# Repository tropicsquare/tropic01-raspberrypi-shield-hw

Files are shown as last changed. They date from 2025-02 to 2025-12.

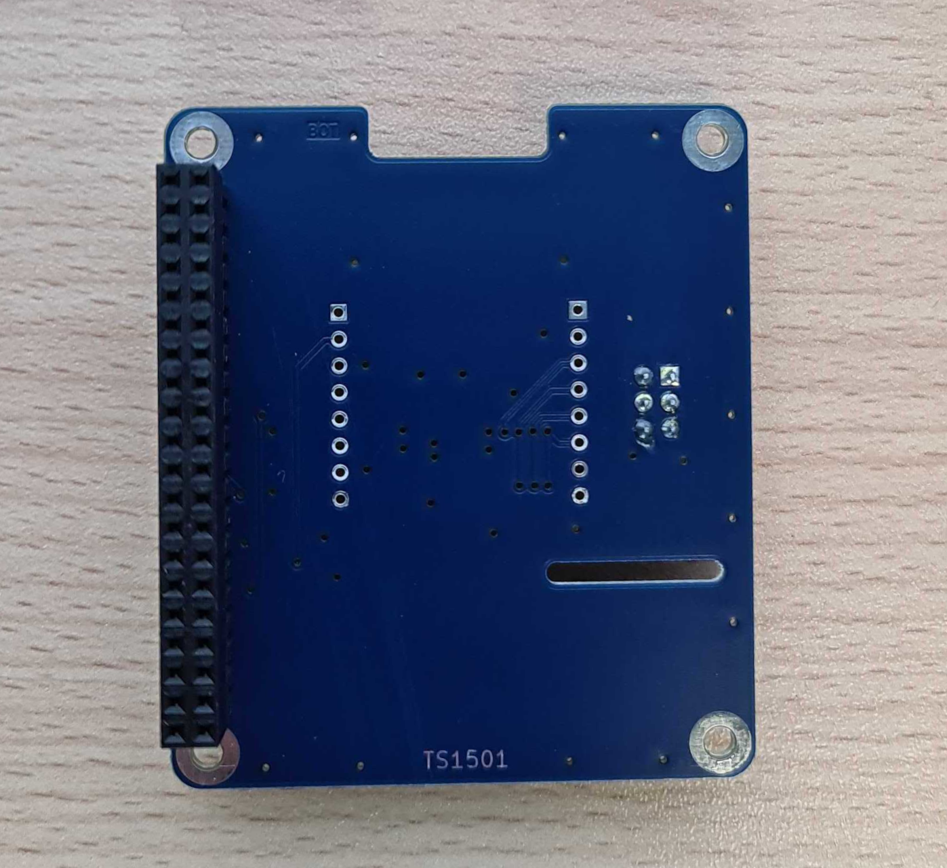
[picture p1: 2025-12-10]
TS1501_design/img/bot_assembled.png

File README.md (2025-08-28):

# TROPIC01 Raspberry Pi Shield

This repository contains the design files for the TROPIC01 development shield, designed for the Raspberry Pi form factor. Each folder corresponds to a specific PCB revision.

### About TROPIC01

For more information about the TROPIC01 secure element, please see the official documentation:

*   [TROPIC01 Datasheet](https://github.com/tropicsquare/tropic01/tree/main/doc/datasheet)
*   [TROPIC01 Website](https://www.tropicsquare.com/tropic01)

# Raspberrypi Shield's Versions

Following table shows all versions of distributed shields.

| hw revision | Picture |
|---|---|
| 1501 |  [Top](./TS1501_design/img/top.png) |

# Getting Started

To interact with the TROPIC01 chip on Linux-based systems like Raspberry Pi OS and Ubuntu, we provide the [`libtropic-linux`](https://github.com/tropicsquare/libtropic-linux) repository, containing integration examples of our platform-independent SDK, [`libtropic`](https://github.com/tropicsquare/libtropic).

 > [!IMPORTANT]
 > Before you start with various examples, we strongly recommend to do two things first:
 > * Read CHIP ID and TROPIC01's firmware versions and **save printed output for future reference**
 > * Update TROPIC01's both internal firmware to latest version.

In [`libtropic-linux`](https://github.com/tropicsquare/libtropic-linux) repository, you can find specifice instruction for both operations based on hardware you use.

### Command line utility

Once you saved results of `show_chip_id_and_fw_ver` example (for future reference) and after your chip is updated with `fw_update` example, you can test our comand line application. Check out [`lt-util`](https://github.com/tropicsquare/libtropic-util) repository, you can find there specifice instruction based on hardware you use.

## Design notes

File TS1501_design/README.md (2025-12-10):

# About

TS15 – TROPIC01 Raspberry Pi Shield
A KiCad-based hardware project designed to connect the TROPIC01 device to a Raspberry Pi via the standard 40-pin GPIO header.

This shield enables straightforward integration of TROPIC01 into Raspberry Pi-based development and testing environments.
It is intended for development, evaluation, and prototyping use.

# Project structure

* `*.kicad_pro` - KiCad project file
* `*.kicad_sch` - Schematic file
* `*.kicad_pcb` - PCB layout file
* `./out/` -  Generated Gerber files for PCB manufacturing
* `./bom/` - Bill of materials, including order codes and interactive BOM
* `./img/` - Images (e.g. PCB renders)
* `*_schematics.pdf` - Exported schematic diagrams (latest version)

# Manufacturing instructions:

## Assembly

IC1/CON1: Chose one variant, assembly IC1 or CON1 (not both on one board).
Chose `bom/bom_variant_*`.

J1: Because the Raspberry Pi has male GPIO pins, the shield's socket must be assembled on the bottom side 
to connect properly when placed on top of the Pi. \

J2: Jumper place to position CS2

There are no any special requirements for C and R components.
Where not specified the R tolerance is 5% and C 20%.

## PCB

* Number of cu layers: 2
* Board Thickness: 1.6
* Core: FR4
* Size: 56 x 65mm
* Mask: Blue
* Silkscreen: Yes (TOP only)

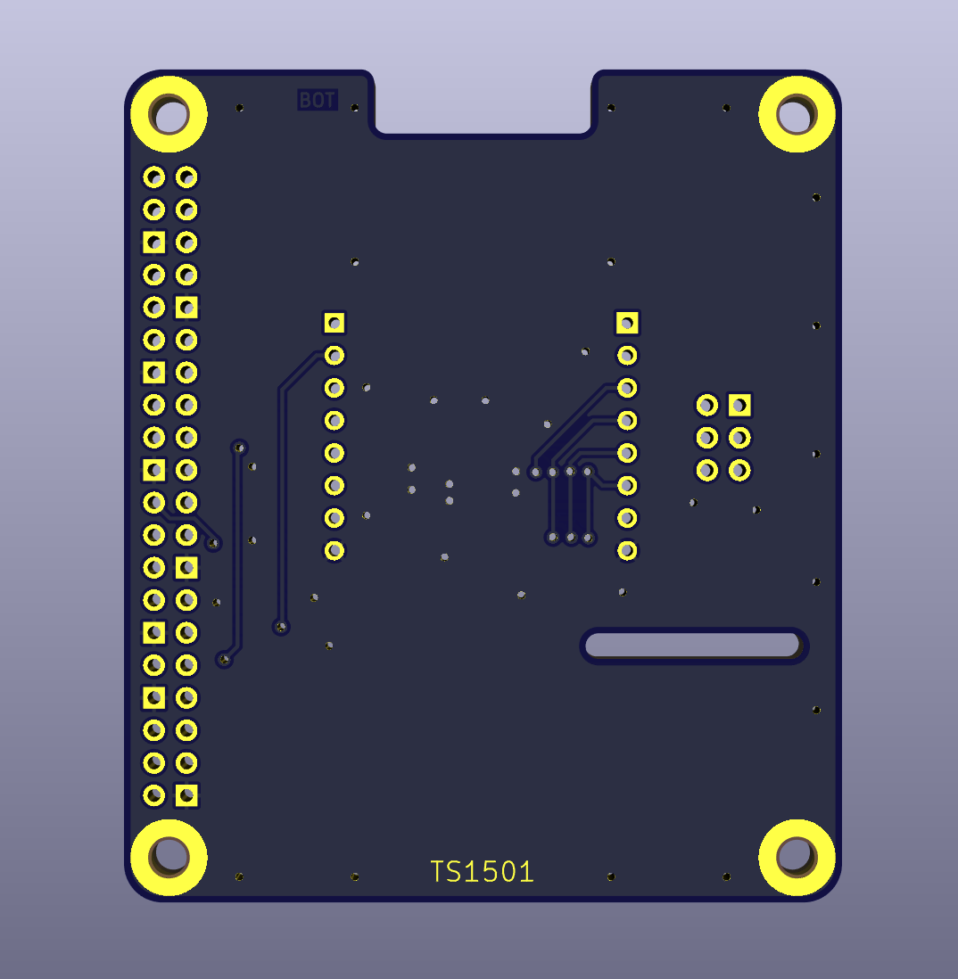
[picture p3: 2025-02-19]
TS1501_design/img/bot.png

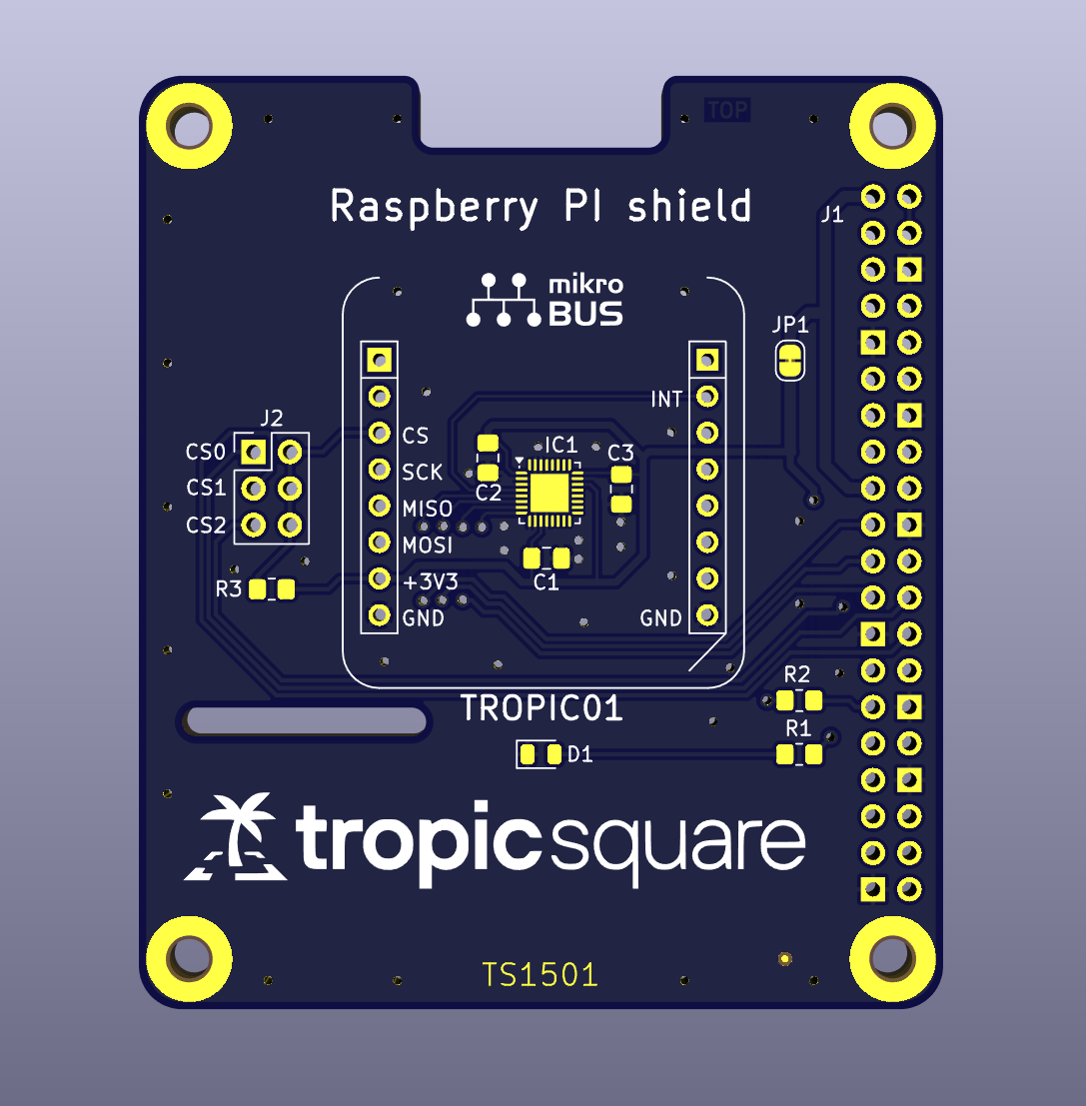
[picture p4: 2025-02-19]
TS1501_design/img/top.png

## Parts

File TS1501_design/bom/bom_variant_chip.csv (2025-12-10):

Reference | Value | Footprint | Qty | DNP | OC_MOUSER
C1,C2,C3 | 100n | Capacitor_SMD:C_0805_2012Metric_Pad1.18x1.45mm_HandSolder | 3 |  | 187-CL21B104KBFNNNE
CON1 | TROPIC01 | ts_mikrobus:TROPIC01_mikrobus | 1 | DNP | dont assemble
D1 | LED_G | LED_SMD:LED_0805_2012Metric | 1 |  | 710-150080GS75000
IC1 | TROPIC01_chip | tropic01_chip:QFN-32-1EP_4x4mm_P0.4mm_EP2.65x2.65mm | 1 |  | TR01-C2P-T103
J1 | RPI socket | shields:RPI_Hat_B+ | 1 |  | 474-PRT-16764
J2 | CS select jumper switch | Connector_PinHeader_2.54mm:PinHeader_2x03_P2.54mm_Vertical | 1 |  | 653-XG8T-0641 + 653-XJ8A-0211
R1,R2 | 1k | Resistor_SMD:R_0805_2012Metric_Pad1.20x1.40mm_HandSolder | 2 |  | 603-RC0805JR-071KL
R3 | 47k | Resistor_SMD:R_0805_2012Metric_Pad1.20x1.40mm_HandSolder | 1 |  | 603-RC0805JR-0747KL

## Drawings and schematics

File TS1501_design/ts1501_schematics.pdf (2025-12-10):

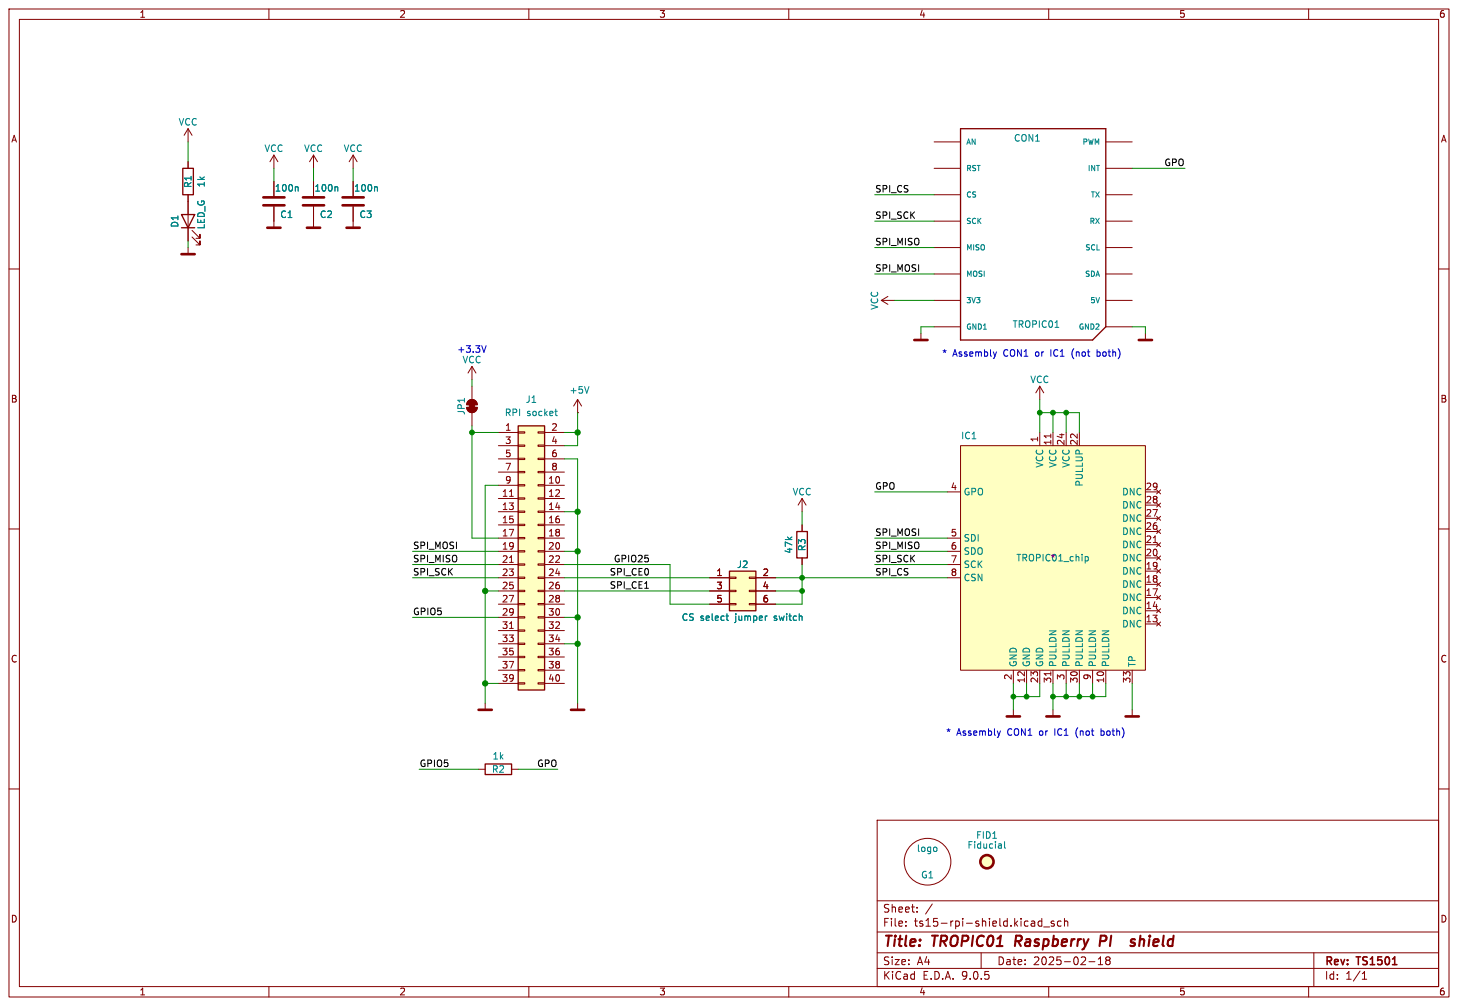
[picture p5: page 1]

File: ts15-rpi-shield.kicad_sch Sheet: /

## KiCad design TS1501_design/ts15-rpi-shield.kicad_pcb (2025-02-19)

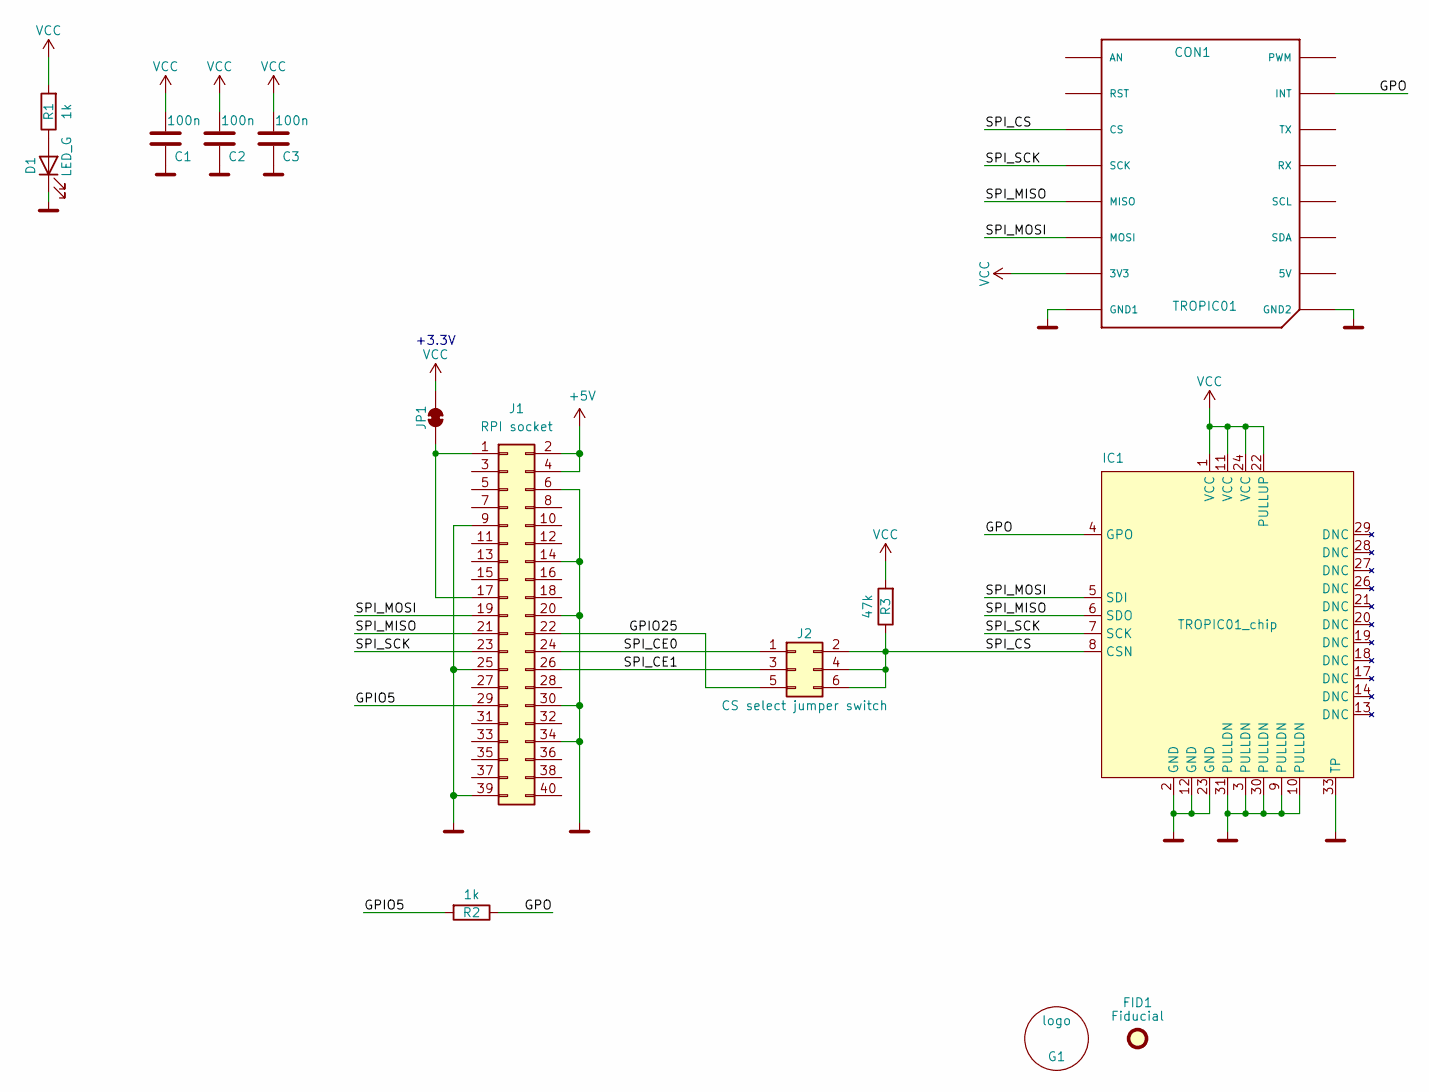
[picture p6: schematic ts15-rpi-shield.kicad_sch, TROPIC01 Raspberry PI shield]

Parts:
C1, C2, C3: 100n; C_0805_2012Metric_Pad1.18x1.45mm_HandSolder
CON1: TROPIC01; TROPIC01_mikrobus
D1: LED_G; LED_0805_2012Metric
FID1: Fiducial; Fiducial_0.5mm_Mask1mm
G1: logo; tropicsquare_logo
IC1: TROPIC01_chip; QFN-32-1EP_4x4mm_P0.4mm_EP2.65x2.65mm
J1: RPI socket; RPI_Hat_B+
J2: CS select jumper switch; PinHeader_2x03_P2.54mm_Vertical
JP1: SolderJumper_2_Bridged; SolderJumper-2_P1.3mm_Bridged
R1, R2: 1k; R_0805_2012Metric_Pad1.20x1.40mm_HandSolder
R3: 47k; R_0805_2012Metric_Pad1.20x1.40mm_HandSolder

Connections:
+5V: J1.2, J1.4
/GPIO5: J1.29, R2.2
/GPIO25: J1.22, J2.5
/GPO: CON1.P15 (INT), IC1.4 (GPO), R2.1
/SPI_CE0: J1.24, J2.1
/SPI_CE1: J1.26, J2.3
/SPI_CS: CON1.P3 (CS), IC1.8 (CSN), J2.2, J2.4, J2.6, R3.1
/SPI_MISO: CON1.P5 (MISO), IC1.6 (SDO), J1.21
/SPI_MOSI: CON1.P6 (MOSI), IC1.5 (SDI), J1.19
/SPI_SCK: CON1.P4 (SCK), IC1.7 (SCK), J1.23
GND: C1.1, C2.1, C3.1, CON1.P8 (GND1), CON1.P9 (GND2), D1.1 (K), IC1.2 (GND), IC1.3 (PULLDN), IC1.9 (PULLDN), IC1.10 (PULLDN), IC1.12 (GND), IC1.23 (GND), IC1.30 (PULLDN), IC1.31 (PULLDN), IC1.33 (TP), J1.6, J1.9, J1.14, J1.20, J1.25, J1.30, J1.34, J1.39
unnamed: D1.2 (A), R1.1
unnamed: J1.1, J1.17, JP1.1 (A)
VCC: C1.2, C2.2, C3.2, CON1.P7 (3V3), IC1.1 (VCC), IC1.11 (VCC), IC1.22 (PULLUP), IC1.24 (VCC), JP1.2 (B), R1.2, R3.2

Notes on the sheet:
+3.3V

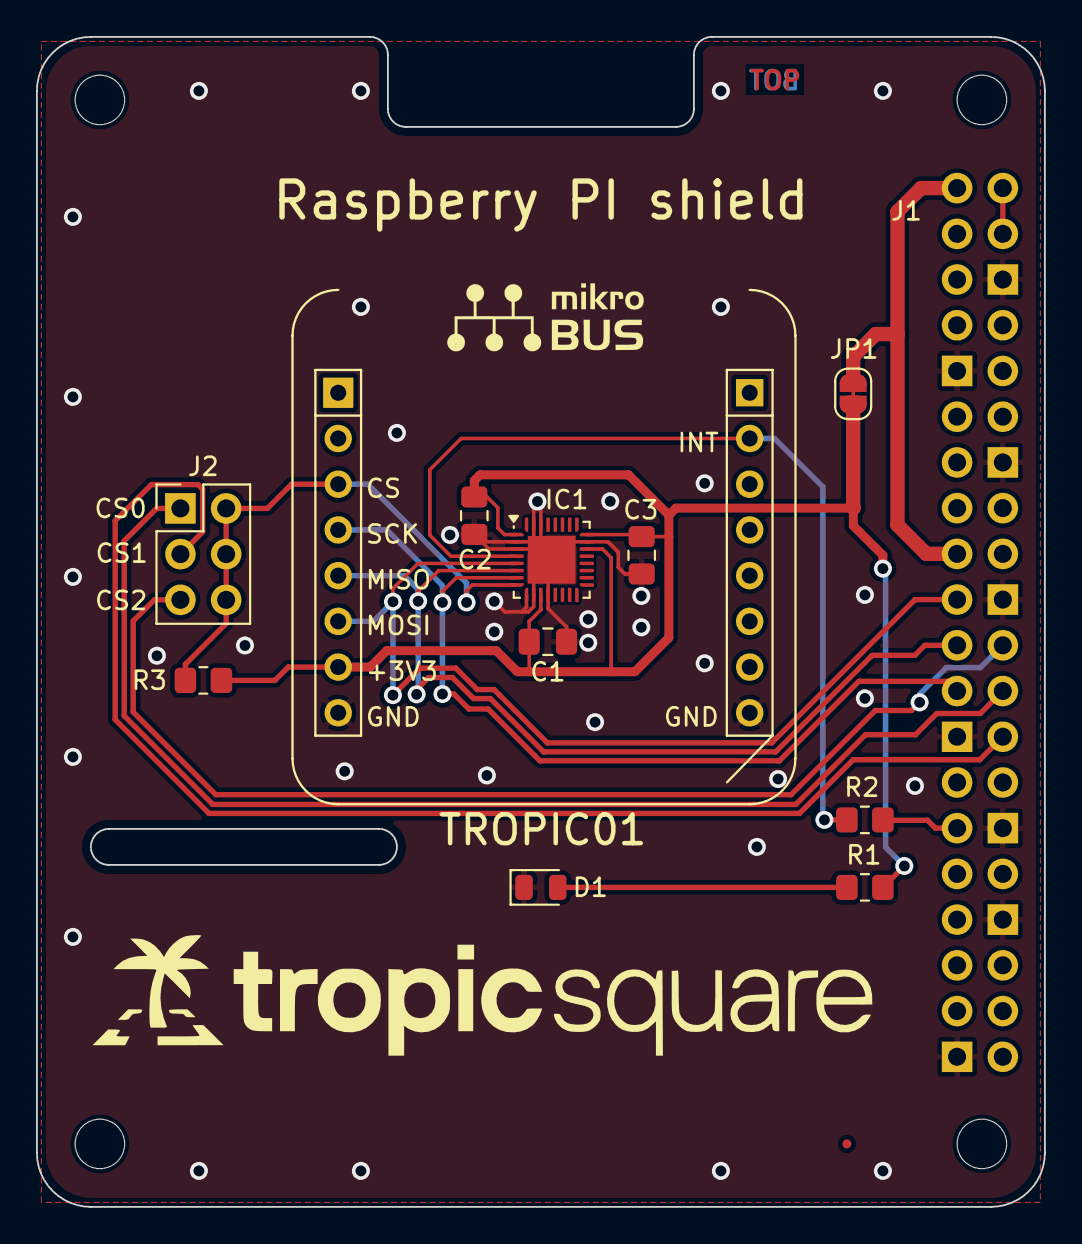
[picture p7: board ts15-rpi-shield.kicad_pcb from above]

Board: 2 copper layers, 56.0 x 65.0 mm, 14 parts (0 on the bottom side), 14 nets.

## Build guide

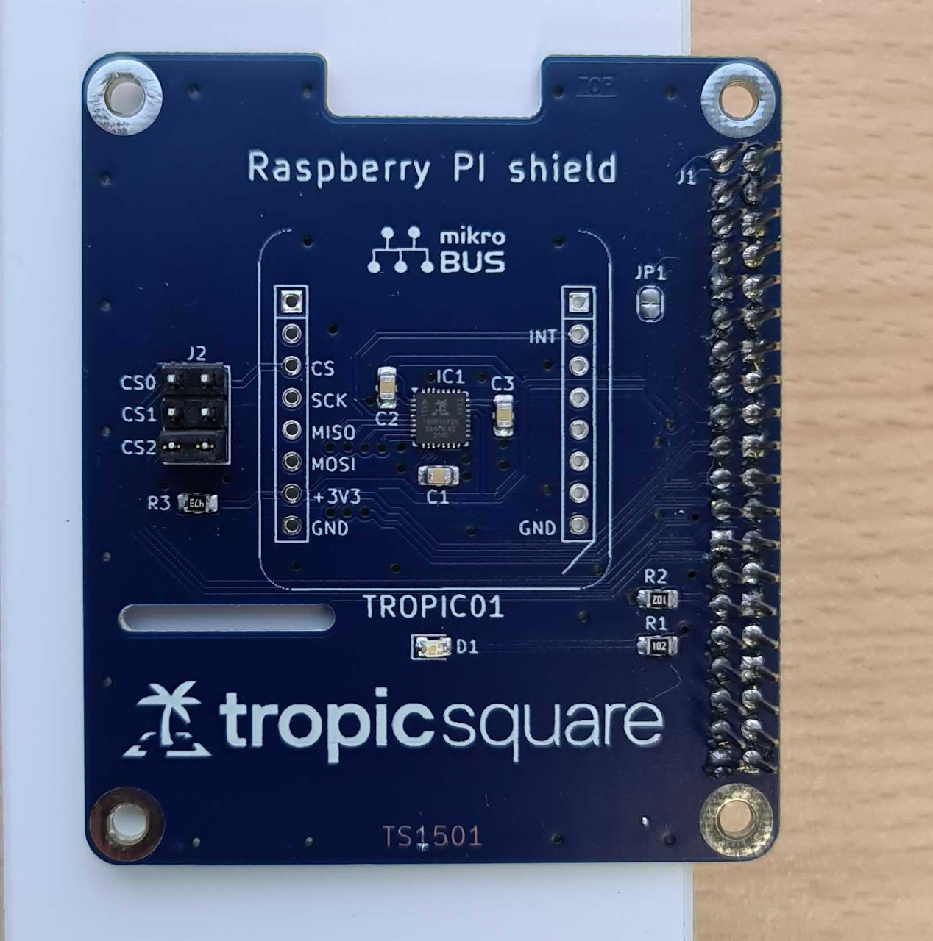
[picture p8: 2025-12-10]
TS1501_design/img/top_assembled.png

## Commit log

2025-02-19 project: Add basic files (schematic and PCB)
    [bom.csv, ts15-rpi-shield.kicad_pcb, ts15-rpi-shield.kicad_sch]
2025-02-19 project: Add fabrication gerber data and some tuning
    [bom.csv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]
2025-05-13 fix: Better part number for RPI shield connector (stackable)
    [bom.csv]
2025-08-28 doc, ref (./) : Readme and repository refactor
    [bom.csv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]
2025-12-10 fix: Update BOM to fix wrong assembly of MIKROE socket
    [bom_variant_chip.csv, bom_variant_microbus.csv, ts15-rpi-shield.kicad_sch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]
